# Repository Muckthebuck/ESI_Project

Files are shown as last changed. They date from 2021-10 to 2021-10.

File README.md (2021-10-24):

# Study Buddy

By:\
Mukul Chodhary  - 1172562\
Matthew Webb    - 1234019\
Mustafa Behrami - 1153524

# VIDEO

[VIDEO](WED_09-00_G2_VID.mov)

## Motive
The study buddy is a smart timer that we created to tackle lockdown studying issues such as phubbing and procrastination. Especially now with the onset of Netflix's newest series Squid Game and new seasons of Lucifer and You, our time management abilities are struggling to cope with the plethora of stimuli being thrown at our brains.

Our project tackles this issue by implementing the pomodoro technique to split work over 25 minute intervals separated by 5 minute breaks. This method rewards effort and progress and has been useful in our university studies previously.

Our plan is to utilise a master slave configuration to overcome pin limitations of a single arduino to connect 4 buttons, an LCD screen, PIR sensor, 8*8 LED matrix and an active buzzer to create the most complete study tool you’ll ever need.

### Physical implementation and 3D design

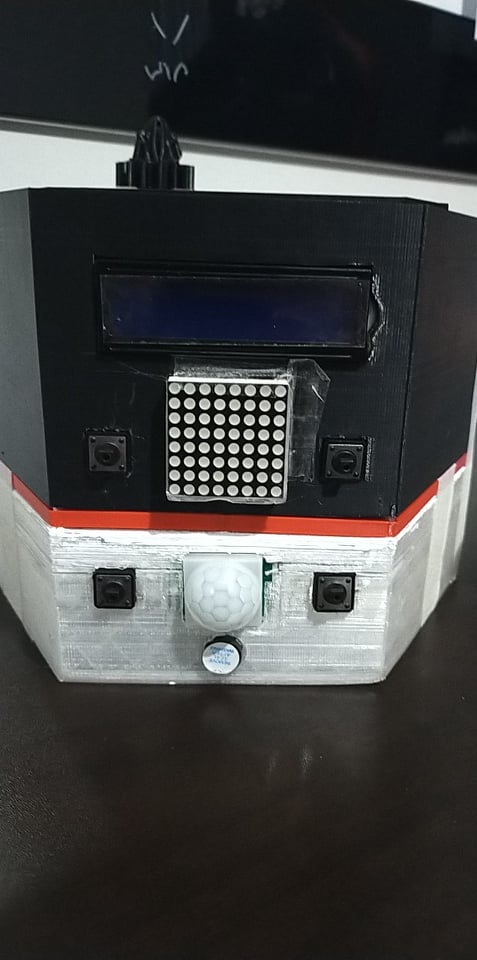
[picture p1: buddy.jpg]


The study buddy was designed with 90’s theme in the back of our mind. The colour scheme, hexagonal shape are the artifacts of that. Autodesk Fusion 360, a computer aided design tool,  was used to design and create the casing. PLA plastic was used to 3D print the study buddy. We decided to go with 3D printer approach, instead of traditional materials like wood because of its ease of reproducibility and real time error fixability. PLA plastic was chosen as our preferred filament for 3D printing over ABS, due to environmental and health concerns. Unlike ABS,  PLA is biodegradable, recyclable, and doesn’t produce any hazardous fumes when melted during printing process. 
Printing and designing prototypes this way is also cost-effective and lets anyone reproduce the product without many difficulties. 

The design of study buddy is modular. It’s made up of three main parts. The top black section, the middle red section and bottom white section. 

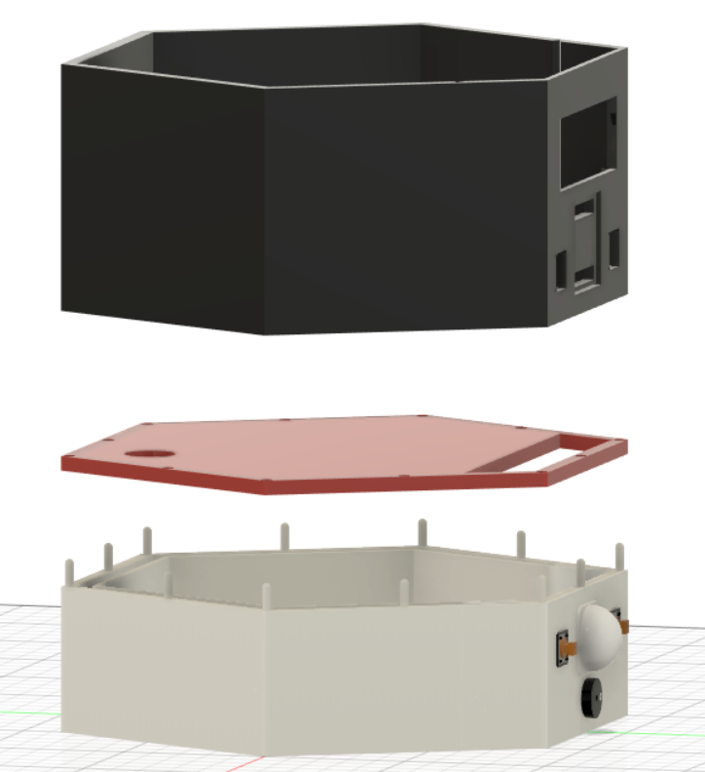
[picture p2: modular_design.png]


The top section contains main user interface, which are : 1 LCD screen capable of displaying 2 lines of 16 characters. 1 8by8 led matrix used to display emotions to make the interaction more human. Two buttons to interact with the system. The user interface is quite simple and intuitive to use. Top section also contains some storage space for your phone, some stationary and maybe some treats !
The middle section splits top and bottom section. This also provides floor for top storage section. 
The bottom section is where both Arduinos live, as well as one DS1302 clock module, stepper motor and its driver, as well as a custom driver for 8by8 led matrix.  and all the wirings. 

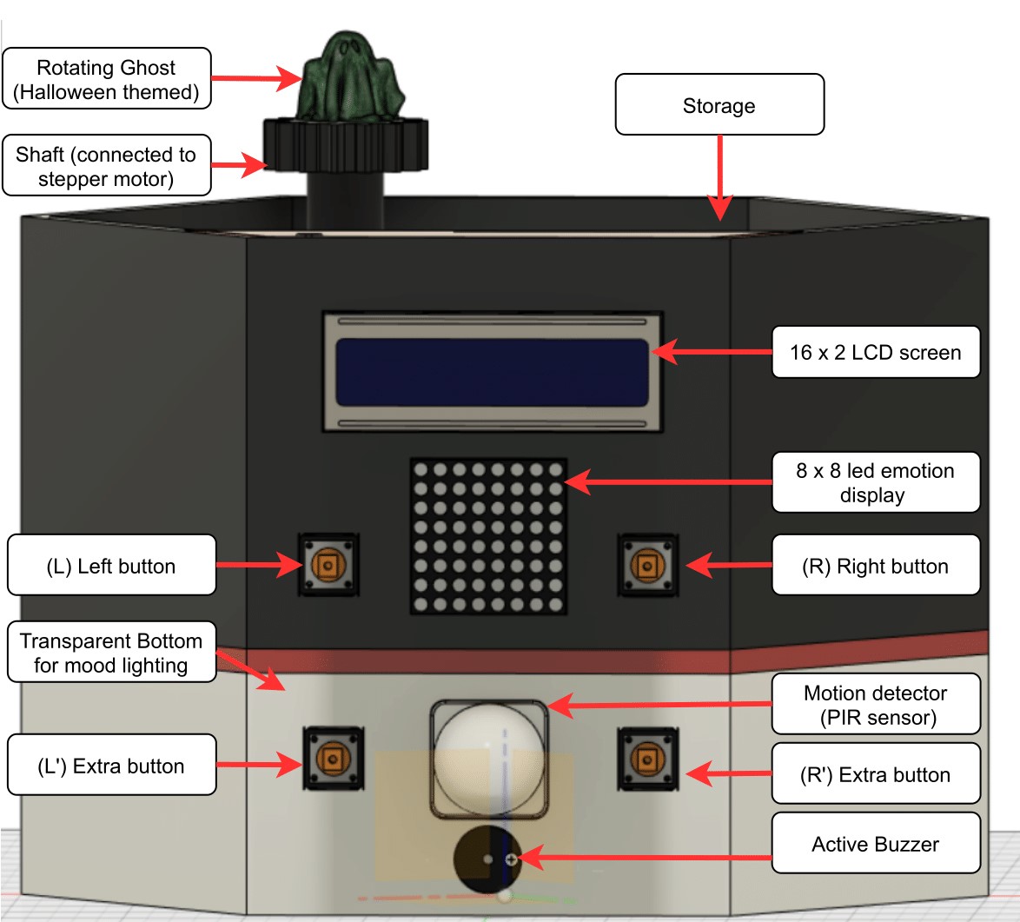
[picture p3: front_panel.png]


More technical viewers might be interested in why we need two Arduinos, and what is this custom driver for 8b8 led matrix. 8by8 led matrix has 16 pin inputs, LCD display requires 12 pin inputs to operate and that’s already too many pins for 1 Arduino to handle. Therefore, we decided to use 2 Arduinos and established an I2C communications between them. 

The master Arduino is connected to all of sensors which are motion sensor (PIR) to detect when user is nearby, Photoresistor (to detect when lights are off),  two user buttons to get input from user, an active buzzer to alert user when timer has ended, and stepper motor for the rotating figure. 
The slave Arduino is responsible for displaying messages to both displays. 16 by 2 LCD screen requires 8 pins to go directly to Arduino and the rest 4 are some combination of VCC and GND pins. But this was still too many pins, as 8by8 led matrix required 16 pins to connect. To reduce number of pins we cascaded 2 8 bit shift registers and created a 16 bit shift register.

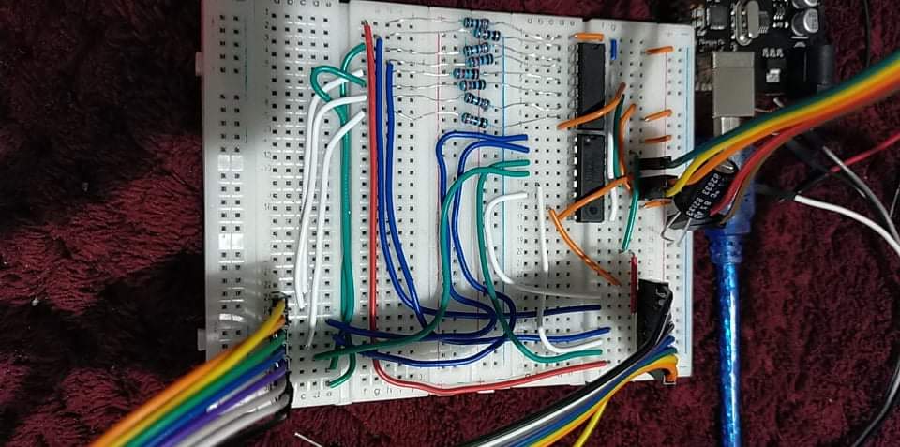
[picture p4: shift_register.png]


This meant we can manipulate 16 pins input to 8 by 8 using only 3 input pins of a shift register. This made our task somewhat manageable. However, the original pins from 8by8 led module were not nicely sorted into rows and columns, so additional wire rerouting had to be done. The driver circuit was built on a breadboard for this project. 

We also recycled some broken garden lights to add warm mood lightings. 



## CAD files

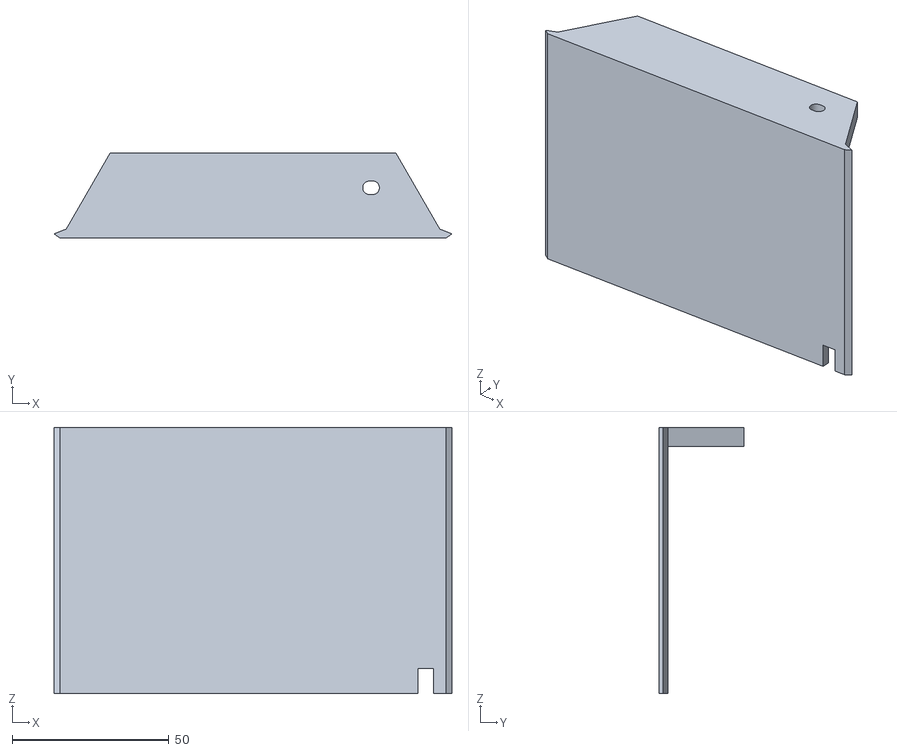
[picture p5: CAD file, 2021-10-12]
3d_models/wire_hiding.stl
126.8 x 27.1 x 84.8

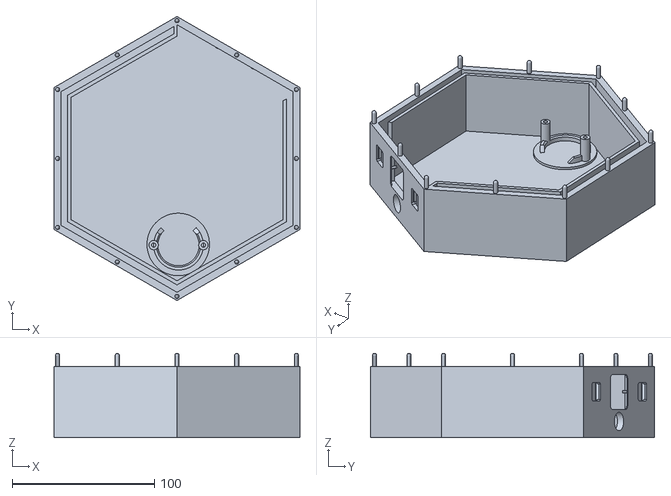
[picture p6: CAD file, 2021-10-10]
3d_models/bottom.stl
173.2 x 200.0 x 59.5

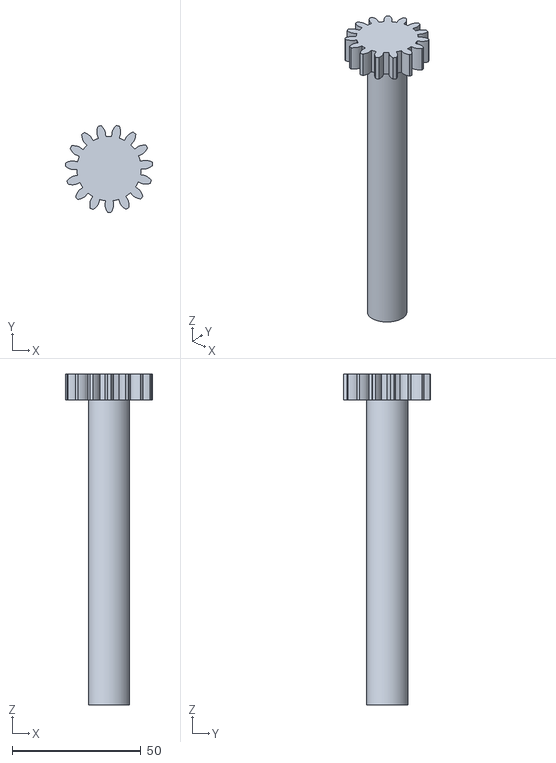
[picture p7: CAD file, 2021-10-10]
3d_models/Motor Gear.stl
33.9 x 33.8 x 128.5

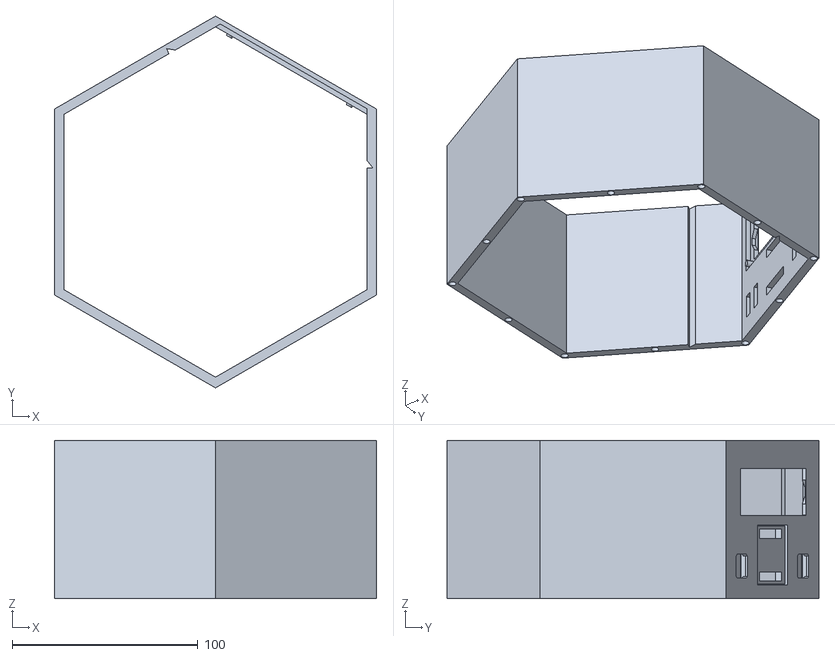
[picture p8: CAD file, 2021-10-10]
3d_models/top.stl
173.2 x 200.0 x 85.0

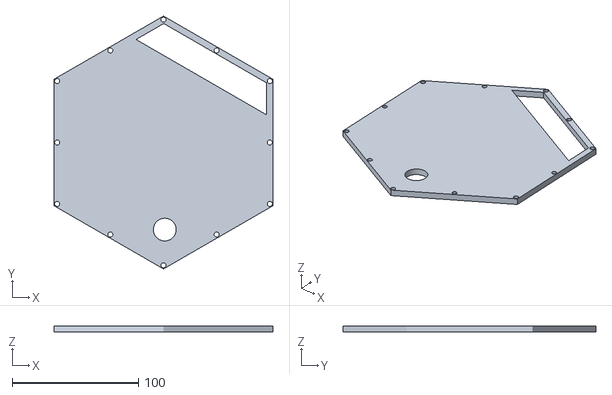
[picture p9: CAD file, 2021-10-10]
3d_models/middle.stl
173.2 x 200.0 x 5.00

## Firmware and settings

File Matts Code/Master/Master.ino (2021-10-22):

#include <virtuabotixRTC.h>
#include <Wire.h>
#include <Stepper.h>
#include <LiquidCrystal.h>
#include <Buzzer.h>

/////////////////////////////////////////// SETUP //////////////////////////////////////

//// LCD
//command
#define LIGHTSOFF 60 
#define LIGHTSON 62

#define SMILE 43
#define SAD 44
#define BORED 45
#define QN 46

// DS1302 controller Pins
// CLK 5, DAT 4, Reset 6
virtuabotixRTC myRTC(5, 4, 6); 

// Photo resistor pin
#define PHOTO_PIN A0
#define PHOTO_THRESHOLD 150

// PIR Sensor Pin
#define PIR_PIN 3

// Active Buzzer Pin
#define ACTIVE_BUZZ_PIN 2
Buzzer buzzer(ACTIVE_BUZZ_PIN);

// Button Pins
#define LEFT_BUTTON_PIN A1
#define RIGHT_BUTTON_PIN A2
#define THIRD_BUTTON_PIN A3


// Arduino Communication
#define SLAVE 9

//stepper motor
// Number of steps per internal motor revolution 
const float STEPS_PER_REV = 32; 
 
//  Amount of Gear Reduction
const float GEAR_RED = 64;
 
// Number of steps per geared output rotation
const float STEPS_PER_OUT_REV = STEPS_PER_REV * GEAR_RED;
 
// Define Variables
 
// Number of Steps Required
int StepsRequired;
 
// Create Instance of Stepper Class
// Specify Pins used for motor coils
// The pins used are 8,9,10,11 
// Connected to ULN2003 Motor Driver In1, In2, In3, In4 
// Pins entered in sequence 1-3-2-4 for proper step sequencing
 
Stepper steppermotor(STEPS_PER_REV, 8, 10, 9, 11);

///////////////////////////////////////// VARIABLES //////////////////////////////////////////

// State Variables
#define NO_MOVEMENT 1
#define READY_FOR_STUDY 2
#define STANDBY 3
#define IN_STUDY 4
#define IN_BREAK 5
#define RESTART 6
int state = 0;
int animation_state=BORED;
// Ready_to_study Variables
bool RTS_message = 0;
int RTS_timer = 5;
unsigned long RTS_previous_time = 0;
unsigned long RTS_wait_time = 60000; // In Milliseconds
int RTS_reminder_hour;
int RTS_reminder_count = 8;

// Cancel Variables
bool cancel_message = 0;
int cancel_timer = 5;

// LCD Overwrite 
bool LCD_overwrite;
String LCD_overwrite_message_top;
String LCD_overwrite_message_bottom;

// Timing Variables for sudo-async functions
unsigned long current_time;
const int am_interval = 1000;
unsigned long am_prev_time = 0;

// Restart Timer Variables
int restart_timer_count = 12;

// Timing Variables for timer
int current_timer_length = 0; // Seconds
int current_timer_time;
unsigned long timer_start_time;
int study_time_duration = 10; // Seconds
int break_time_duration = 5; // Seconds

String prev_message="";
// Animation variables
 int previous_animation;
int current_animation;

// Sensor/button trigger status
bool left_btn = 0;
bool right_btn = 0;
bool third_btn = 0;
bool photo_input = 0;
bool enough_light = 0;
bool PIR = 0;
char data[32];
int light_state = 1;
int stepper_state=0;
// Messages
const int random_string_limit = 10;
int random_string_timer = 0;
int random_string_number;
String random_message[] = {"Hello world", "maybe study?", "No youtube :("};
int random_message_loop_count = 0;

//functions

int RTS_has_time_passed(unsigned long current_time);
int is_enough_light();
void cancel_cancel_message();
void cancel_RTS_message();
void go_to_cancel_message();
void go_to_ReadyToStudy_message();
int RTS_reminder_remaining();
void go_to_standby();
void break_timer_finished();
void study_timer_finished();
void update_current_timer_time();
void start_timer();
void ready_to_study();
void reset_inputs();
int detected_movement();
void LCD_print(String top_message, String bottom_message);
String format_string_for_print(String str);
void local_LCD_display(String message);
String get_day_and_time();
String leading_zero(uint8_t val);
void buzzer_tone();
void happy_jingle();
void bl_lcd_control(uint16_t val);
String random_string();
String seconds_to_mmss(int seconds);
void serial_print_time();
void action_manager();
void toggle_lights(int state);

void setup() {
 // Serial.begin(9600);
  // Begin Arduino Communication
  Wire.begin();
  //sec,min,hour,dayoftheweek,month,day,year
  //myRTC.setDS1302Time(00,31,11,3,10,19,2021);
  pinMode(PIR_PIN, INPUT);
  pinMode(PHOTO_PIN, INPUT);
  pinMode(ACTIVE_BUZZ_PIN, OUTPUT);
  pinMode(LEFT_BUTTON_PIN, INPUT);
  pinMode(RIGHT_BUTTON_PIN, INPUT);
  pinMode(THIRD_BUTTON_PIN, INPUT);
  state = STANDBY;
  reset_inputs();
  RTS_reminder_hour = myRTC.hours;
}

void loop() {
  check_inputs();
  action_manager();
  //rotate_motor
}

void check_inputs() {
    if (digitalRead(LEFT_BUTTON_PIN)){
      left_btn = 1;
    }
    if (digitalRead(RIGHT_BUTTON_PIN)){
      right_btn = 1;
    }
    if (digitalRead(PIR_PIN)){
      PIR = 1;
    }
}


void action_manager(){
  // https://docs.google.com/document/d/1u9RpGDv0Du3XHBDmag-IDaQyKIT7uMIzJ4LOqx1lm7U/edit#heading=h.sil5lysrvarm
  // Limits how quickly this function happens.
  current_time = millis();
  if ((unsigned long)(current_time - am_prev_time) >= am_interval){
      am_prev_time = current_time;
  } else {
    return;
  }

  // Check Photoresistor, if high, turn on screen, otherwise exit action manager.
  if(is_enough_light()==0){ 
    toggle_lights(LOW);
    reset_inputs();
    return;
  } else {
   toggle_lights(1);
    StepsRequired  =  -STEPS_PER_OUT_REV / 2;
    steppermotor.setSpeed(800);   
    steppermotor.step(StepsRequired);
  }

  // Update time on RTC
  myRTC.updateTime(); 

  // Cancel message state logic
  if(cancel_message==1){
    cancel_timer--;
    if (right_btn==1){
      cancel_cancel_message();
      go_to_standby();
    } else if (cancel_timer<0){
     // change_animation(previous_animation); 
      cancel_cancel_message();
    } else {
      LCD_overwrite=1;
      LCD_overwrite_message_bottom = ((String)cancel_timer + " s to confirm");
      LCD_print("","");
    }
  }

  // Ready to study state logic
  if(RTS_message==1){
    RTS_timer--;
    if (left_btn==1){
      cancel_RTS_message();
      start_timer();
    } else if (right_btn){
      cancel_RTS_message();
      go_to_standby();
    } else if (RTS_timer<0){
      cancel_RTS_message();      
    } else {
      LCD_overwrite = 1;
      animation_state = QN;
      LCD_overwrite_message_top = get_day_and_time();
      LCD_overwrite_message_bottom = ("Study? L(Y):R(N)");
      LCD_print("","");
    }
  }

  // Standby State logic
  if(state==STANDBY){
    animation_state = BORED;
    if (detected_movement()&&RTS_has_time_passed(current_time)){
      // Restrict PIR message to 8 per hour
      if (RTS_reminder_remaining() > 0){
        // continue
         go_to_ReadyToStudy_message();
      }
    }
    if (left_btn||right_btn){
      go_to_ReadyToStudy_message();
    } else {
      LCD_print(get_day_and_time(),random_string());
    }
  }

  // In timer state logic
  if(state==IN_STUDY){
    animation_state = SMILE;
    update_current_timer_time();
    if (cancel_message==0&&(left_btn||right_btn)){
      go_to_cancel_message();
    }
    if (current_timer_time >= 0){
      LCD_print(get_day_and_time(),("Timer: " + seconds_to_mmss(current_timer_time)));
    } else {
      study_timer_finished();
    }
  }

  // In break state logic
  if(state==IN_BREAK){
    update_current_timer_time();
    if (cancel_message==0&&(left_btn||right_btn)){
      go_to_cancel_message();
    }
    if (current_timer_time >= 0){
      LCD_print(get_day_and_time(), ("Break: " + seconds_to_mmss(current_timer_time)) );
    } else {
      break_timer_finished();
    }
  }

  // Restart state logic
  if(state==RESTART){
    restart_timer_count--;
    if (left_btn){
      reset_inputs();
      restart_timer_count = 12;
      start_timer();
    } else if (restart_timer_count==0 || right_btn){
      reset_inputs();
      restart_timer_count = 12;
      go_to_standby();
    }
  }
  
}

////////////////////// FUNCTIONS ///////////////////////////

// Check if enough time has passed between PIR activated Ready to study messages
int RTS_has_time_passed(unsigned long current_time){
  // Check if we are within first 60 seconds <- this is an edge case
  if (RTS_previous_time == 0){
    RTS_previous_time = current_time;
    return 1;
  }
  
  if ((unsigned long)(current_time - RTS_previous_time) >= RTS_wait_time){
    RTS_previous_time = current_time;
    return 1;
  } else {
    return 0;
  }
}

// Check if the Photo resistor is above the threshold
int is_enough_light(){
  if (analogRead(PHOTO_PIN)<PHOTO_THRESHOLD){
    return 0;
  } else {
    return 1;
  }
}

// Exit cancel message
void cancel_cancel_message(){
  reset_inputs();
  cancel_message = 0;
  LCD_overwrite = 0;
  cancel_timer = 5;
}

// Exit Ready to study message
void cancel_RTS_message(){
  animation_state = QN;
  reset_inputs();
  RTS_message = 0;
  LCD_overwrite = 0;
  RTS_timer = 5;
}

// Display cancel message
void go_to_cancel_message(){
     animation_state = QN;
  // change_animation(QN);
  reset_inputs();
  cancel_message = 1;
  LCD_overwrite = 1;
  LCD_overwrite_message_top = "End timer?: R(Y)";
  LCD_overwrite_message_bottom = ((String)cancel_timer + " s to confirm");
  LCD_print("","");  
}

// Display Ready to study message
void go_to_ReadyToStudy_message(){
   animation_state = QN;
 // change_animation(QN);
  reset_inputs();
  RTS_message = 1;
  LCD_overwrite = 1;
  LCD_overwrite_message_top = get_day_and_time();
//  animation_state = QN;
  LCD_overwrite_message_bottom = ("Study? L(Y):R(N)");
  LCD_print("","");
}

// Return how many reminders are remaining. Limited to 8 per hour from the PIR
// This function does not get used when RTS message is activated from hitting left or right
int RTS_reminder_remaining(){
  if (RTS_reminder_hour != myRTC.hours){
    RTS_reminder_hour = myRTC.hours;
    RTS_reminder_count = 8;
  } else if (RTS_reminder_count == 0){
  } else {
    RTS_reminder_count--;
  }
  return RTS_reminder_count;
}

// Switch to standby state
void go_to_standby(){
  //animation_state = BORED;
  state=STANDBY;
  reset_inputs();
  animation_state = BORED;
 // change_animation(BORED);
}

// Break Timer has finished, transition to RESTART state
void break_timer_finished(){
  reset_inputs();
  buzzer_tone();
  LCD_print("Restart timer?","L(Y):R(N)");
  state = RESTART;
}

// Study Timer has finished, transistion to BREAK state
void study_timer_finished(){
  animation_state = QN;
  state = IN_BREAK;
  timer_start_time = millis();
  current_timer_length = break_time_duration;
  current_timer_time = break_time_duration+1;
  happy_jingle();
  LCD_print(get_day_and_time(), ("Break: " + seconds_to_mmss(current_timer_time)) );
}

// Updates timer count. I guess we can get more accurate by adding checking against the RTC
void update_current_timer_time(){
  //int time_elapsed = (current_time - timer_start_time)/1000; // time elapsed in seconds
  //current_timer_time = current_timer_length - time_elapsed;
  current_timer_time--;
}

// Start the timer!
void start_timer(){
  animation_state = SMILE;
  state = IN_STUDY;
  reset_inputs();
  timer_start_time = millis();
  current_timer_length = study_time_duration;
  current_timer_time = study_time_duration+1;
  LCD_print(get_day_and_time(),("Timer: " + seconds_to_mmss(current_timer_time)));
}

// Resets all the inputs so we can get some fresh data
void reset_inputs(){
  PIR=0;
  left_btn=0;
  right_btn=0;
}

// How we detect movement
int detected_movement(){
  if(PIR==1){
    return 1;
  } else {
    return 0;
  }
}

// Send message to other arduino to change the state of the backlight
void toggle_lights(int next_state){
  Wire.beginTransmission(SLAVE);
  if(light_state!=next_state){
    light_state=next_state;
    if(next_state ==1){
      Wire.write((char)LIGHTSON);
    }else{
      Wire.write((char)LIGHTSOFF);
    }
     Wire.endTransmission(SLAVE);
  }
}

// Send a message to other arduino to change animation
void change_animation(int animation){
  previous_animation = current_animation;
  current_animation = animation;
  Wire.beginTransmission(SLAVE);
  Wire.write(animation);
  Wire.endTransmission(SLAVE);
}

// Send a string to the other arduino to Display a message
void LCD_print(String top_message, String bottom_message){
  String top = format_string_for_print(top_message);
  String bottom = format_string_for_print(bottom_message);
  String full_message;
  if (LCD_overwrite){
    full_message = format_string_for_print(LCD_overwrite_message_top)+format_string_for_print(LCD_overwrite_message_bottom);
  } else {
    full_message = top+bottom;
  }
  full_message[31]= animation_state;
  if(prev_message!=full_message){
    
    prev_message = full_message;
       Wire.beginTransmission(SLAVE); // transmit to device #9
    for(int i=0; i<32; i++){
      Wire.write(full_message[i]);
    }
    Wire.endTransmission(SLAVE);
  }
 
}

// Format a string to be exactly 16 characters by adding spaces
String format_string_for_print(String str){
  // Formats a string to be exactly 16 characters
  int str_length = str.length();
  if (str_length>16){
  //  Serial.println("Problem with string");
    return "String Too Long";
    // Invalid input
  }
  
  String temp_str= "";
  
  for (int i=0; i<str_length; i++){
    temp_str.concat(str[i]);
  }
  for (int i=str_length; i<16; i++){
    temp_str.concat(" ");
  }
  return temp_str;
}

// Returns the day then time
String get_day_and_time(){
  int day_number = myRTC.dayofweek;
  String day_of_week;
  String output_string;
  if (day_number == 1) {
    day_of_week = "Sunday   ";
  } else if (day_number == 2){
    day_of_week = "Monday   ";
  } else if (day_number == 3){
    day_of_week = "Tuesday  ";
  } else if (day_number == 4){
    day_of_week = "Wednesday";
  } else if (day_number == 5){
    day_of_week = "Thursday ";
  } else if (day_number == 6){
    day_of_week = "Friday   ";
  } else if (day_number == 7){
    day_of_week = "Saturday ";
  } 
  output_string = (day_of_week +" " +leading_zero(myRTC.hours) + ":" + leading_zero(myRTC.minutes));
  return output_string;
}

// Adds a leading zero to a single digit number
String leading_zero(uint8_t val){
    if (val < 10)   // <10 = 09, 08, 07, 06, 05, 04, 03, 02, 01, 00 
    {
       return ("0" + (String)val);
    }
    return (String)val; 
}

void serial_print_time(){
  Serial.print("Current Date / Time: ");
  Serial.print(myRTC.dayofmonth); 
  Serial.print("/");
  Serial.print(myRTC.month);
  Serial.print("/");
  Serial.print(myRTC.year);
  Serial.print(" ");
  Serial.print(myRTC.hours);
  Serial.print(":");
  Serial.print(myRTC.minutes);
  Serial.print(":");
  Serial.println(myRTC.seconds);
}

// Converts an amount of seconds to mm:ss
String seconds_to_mmss(int seconds){
  uint8_t timer_mins = seconds/60;
  uint8_t timer_secs = seconds%60;
  return (leading_zero(timer_mins)+":"+leading_zero(timer_secs));
}

// Returns a random string
String random_string(){
  if (random_string_timer > random_string_limit){
    random_string_number = random(0,3);
    random_string_timer = 0;
  } else {
    random_string_timer++;
  }
  return random_message[random_string_number];
}

void happy_jingle(){
  buzzer.begin(0);

  buzzer.sound(NOTE_D5, 260);
  buzzer.sound(NOTE_DS5, 520);
  buzzer.sound(NOTE_GS5, 260);
  buzzer.sound(NOTE_F5, 520);
  buzzer.sound(NOTE_D5, 260);
  buzzer.sound(NOTE_DS5, 520);
  buzzer.sound(NOTE_GS5, 800);
  buzzer.sound(NOTE_F5, 1000 );  
  
  buzzer.end(100);
}

void buzzer_tone(){
  buzzer.begin(0);
  buzzer.sound(NOTE_D5, 260);
  buzzer.sound(0, 260);
  buzzer.sound(NOTE_D5, 260);
  buzzer.sound(0, 260);
  buzzer.sound(NOTE_D5, 260);
  buzzer.sound(0, 260);
  buzzer.sound(NOTE_D5, 260);
  buzzer.sound(0, 260);
  
  buzzer.end(100);
}

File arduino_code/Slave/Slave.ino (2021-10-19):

// I2C Slave

// Include the required Wire library for I2C
#include <Wire.h>
#include <LiquidCrystal.h>
//commands
#define LIGHTSOFF 60 
#define LIGHTSON  62
int lights=1;

//8by8 array
#define DATA 2
#define SHIFT 3
#define STORE 4

#define SMILE 43
#define SAD 44
#define BORED 45
#define QN 46

//time keeping variables
int STORE_period = 10;
unsigned long STORE_prev_time1 = 0;
unsigned long STORE_prev_time2 = 0;
unsigned long ANIMATION_prev_time = 0;

int Store_high=0;
const int columns = 8;
int animation_state=BORED;
void animation(int movie[][columns]);
void store();
const int frames = 6;
const int smile[frames][8] = {{0,36,36,36,0,66,60,0},
                 {0, 0,36,0, 0, 0,24,0},
                 {0, 0,36,0, 0, 0,24,0},
                 {0, 0,36,0, 0, 0,60,0},
                 {0, 0,36,0, 0, 0,60,0},
                 {0,36,36,36,0,66,60,0}};
const int sad[frames][8] = {{0, 0,36,36, 0, 0,24,0},
                          {0, 0,36,0, 0, 0,24,0},
                          {0, 0,36,36, 0, 0,60,66},
                          {0, 0,36,0, 0, 0,60,66},
                          {0, 0,36,36, 0, 0,60,66},
                          {0, 0,36,0, 0, 0,60,66}};
                               
const int bored[frames][8] = {{0, 0,36,0, 0, 0,24,0},
                         {0, 0,102,0, 0, 0,24,0},
                         {0, 0,102,0, 0, 0,24,0},
                         {0, 0,102,0, 0, 0,60,0},
                         {0, 0,102,0, 0, 0,60,0},
                         {0, 0,102,0, 0, 0,126,0}}; 

const int question[frames][8]={{28, 34,2,12, 8, 0,0,0},
                         {28, 34,2,12, 8, 0,8,0},
                         {28, 34,2,12, 8, 0,0,0},
                         {28, 34,2,12, 8, 0,8,0},
                         {28, 34,2,12, 8, 0,0,0},
                         {28, 34,2,12, 8, 0,8,0}};              

const int LED = 13;
char lcd_message_buff[32];
String LCD_message = "";
String x = "";
char buff[16];
int event;
char data[32];
/*
 * pin layout
 * 7 - A, to turn on backlight
 * 8 - RS pin
 * 9 - Enable pin
 * 10 - D4
 * 11 - D5
 * 12 - D6
 * 13 - D7
 */
int next=0;
//initialise LCD library
const int rs = 8, en =9, d4 = 10, d5=11, d6=12, d7=13, lcd_on=7;
LiquidCrystal lcd(rs,en,d4,d5,d6,d7);

byte Heart[8] = {
0b00000,
0b01010,
0b11111,
0b11111,
0b01110,
0b00100,
0b00000,
0b00000
};

void setup() {
  // Define the LED pin as Output
 // Serial.begin(9600);
  //8by8 led matrix
   pinMode(DATA, OUTPUT);
   pinMode(SHIFT, OUTPUT);
   pinMode(STORE, OUTPUT);
  //lcd
  pinMode(lcd_on, OUTPUT);
  lcd.begin(16,2);
  delay (500);
  lcd.createChar(0, Heart);
  lcd.clear();
  // Start the I2C Bus as Slave on address 9
  Wire.begin(9); 
  // Attach a function to trigger when something is received.
  event=0;
  Wire.onReceive(receiveEvent);
  turn_on();
}

void receiveEvent(int bytes) {
  x ="";
  while( Wire.available()){
    lcd.setCursor(0,0);
   // sprintf(buff,"recieved");
    x += (char)Wire.read(); // read from the I2C
  } 
  event=1;
  if(x==""){
    event=0;
  }
}

void loop() {
   //lcd.clear();
  if(event==1){
   // Serial.println(x);
    if((int)x[0]==LIGHTSOFF){
      lights=0;
      turn_off();
    }else if((int)x[0]==LIGHTSON){ 
      lights=1;
      turn_on();
//    }else if((int)x[0]==SMILE||(int)x[0]==SAD||(int)x[0]==BORED||(int)x[0]==QN){
//      Serial.println((int)x[0]);
//      if((int)x[0] == SMILE){
//        animation_state = SMILE;
//      }else if((int)x[0] == SAD){
//       animation_state = SAD;
//      }else if((int)x[0] == BORED){
//       animation_state = BORED;
//      }else if((int)x[0]== QN){
//       animation_state = QN;
//      } 
    }else{
     //  Serial.println(x);
     if(x!=LCD_message){
      x.toCharArray(lcd_message_buff, 33);
      animation_state = (int)lcd_message_buff[31];
      if(lcd_message_buff[30]=='N'){
        animation_state = QN;
      }else if(x.substring(16,21)=="Break"){
        animation_state = SMILE;
      }else if(x.substring(0,3) == "End"){
         animation_state = SAD;
      }
       local_LCD_display(lcd_message_buff);  
     }
    }
 }
  if(lights){
    if(animation_state == SMILE){
      animation(smile);
    }else if(animation_state == SAD){
     animation(sad);
    }else if(animation_state == BORED){
     animation(bored);
    }else if(animation_state== QN){
     animation(question);
    } 
   }
  
//  if(lights){
//    animation(smile);
//   }
 // delay(1000);
 // lcd.clear(); 
}

void turn_on(){
  digitalWrite(lcd_on, HIGH);
}

void turn_off(){
  lcd.clear(); 
  digitalWrite(lcd_on, LOW);
}

void local_LCD_display(char data[32]){
  // lcd.clear(); 
  // message.toCharArray(data, 33);
  // Serial.print(" inside lcd function ");
   //Serial.println(data);
   data[31]=' ';
   if(data[30]=='N'){
    data[31]=')';
   }
   int i;
    for(i=0;i<16;i++){
      lcd.setCursor(i,0);
      lcd.write(data[i]);
    }   
    for(i=16;i<32;i++){
      lcd.setCursor(i-16,1);
      lcd.write(data[i]);
    }
}

void change_animation(String x){
  
}

void animation(const int movie[][columns]){
  int j=0;
    //if ((unsigned long)(micros() - ANIMATION_prev_time >= 100)&& j<frames){
      for(j=0;j<frames;j++){
       for(int k=0;k<100;k++){
          for (int i=0; i<8; i++) {
           shiftOut(DATA, SHIFT, LSBFIRST, ~movie[j][i]);
           shiftOut(DATA, SHIFT, LSBFIRST, 128 >> i);
 //          store2();
             if((unsigned long)(micros()-STORE_prev_time1) >= STORE_period){
                  digitalWrite(STORE, HIGH);
                STORE_prev_time1=micros();
              }
              if((unsigned long)(micros()-STORE_prev_time2) >= 2*STORE_period){
                digitalWrite(STORE, LOW);
                STORE_prev_time2=micros();
              }
         }
    // j++;
       // ANIMATION_prev_time = micros();
        }
    } 
}
void store2() {
  digitalWrite(STORE, HIGH);
  delayMicroseconds(10);
  digitalWrite(STORE, LOW);
  delayMicroseconds(10);
}

void store() {
  unsigned long current_time = micros();
  if((unsigned long)(current_time-STORE_prev_time1) >= STORE_period){
      digitalWrite(STORE, HIGH);
    STORE_prev_time1=current_time;
  }
  if((unsigned long)(current_time-STORE_prev_time2) >= 2*STORE_period){
    digitalWrite(STORE, LOW);
    STORE_prev_time2=current_time;
  }
}

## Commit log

2021-09-20 I2c communication
2021-10-02 Added buggy cancel timer
    Things added:
    - active buzzer turns on with 1 second left on study timer (for 1 second duration)
    - slightly (very) buggy cancel function
    To do:
    - fix sticky right button (cancel button) so the initialisation timer isn't affected by it after being pressed in the initialisation countdown
    - Add comments to new code
2021-10-09 stl files
    3d models
    [Motor Gear.stl, bottom.stl, middle.stl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]
2021-10-10 Finished timer
    Added:
    - Proper cancel timer function without bugs
    - Auto cancel the study mode after 12 seconds of inactivity in post break period
    Need to do:
    - implement external buttons and not LCD shield buttons
2021-10-12 ghost stl
    [wire_hiding.stl]
